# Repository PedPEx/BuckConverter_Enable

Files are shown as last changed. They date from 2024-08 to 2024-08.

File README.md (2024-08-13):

# BuckConverter with Enable Input (WIP!)
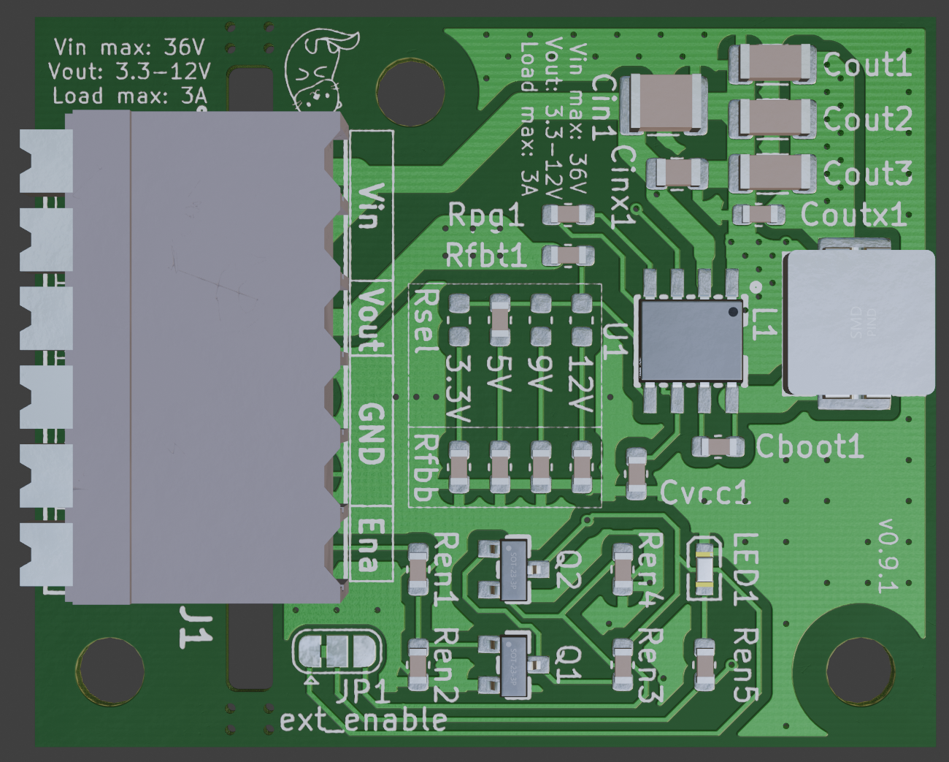
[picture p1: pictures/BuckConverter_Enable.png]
v0.9.1 a title


A BuckConverter based on the [Texas Instruments LM33630](https://www.ti.com/product/LMR33630). By default the converter is set to an output voltage of 5V and enabled permanently. Avaliable output levels are 3.3 V, 5 V, 9 V and 12 V. In order to select the desired output, only the corresponding `Rsel` 0 ohm resistor/connection has to be installed. 

The external enable input is enabled by cutting the builtin connection in `J1` and connectiong the solder bridge in the other direction. 

It's possible to use a [Weidmüller 1824460000 - LSF-SMT 3.50/06/90 3.5SN BK TU](https://catalog.weidmueller.com/catalog/Start.do?ObjectID=1824460000), a [PhoenixContact 1861975 - SPTAF 1 6-3,5-IL](https://www.phoenixcontact.com/de-de/produkte/leiterplattenklemme-sptaf-1-6-35-il-1861975) or a [screw terminal block from LCSC](https://www.lcsc.com/product-detail/Screw-Terminal-Blocks_DORABO-DB127S-3-5-6P-GN-S_C2997513.html) for J1. A standard 3.5 mm pitch pin header is also possible.

[Online BOM](https://htmlpreview.github.io/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)

---
**Note**

The pictures were rendered with the help of Blender and the [pcb2blender](https://github.com/30350n/pcb2blender) plugin and the HTML BOM was created withwith [InteractiveHtmlBom](https://github.com/openscopeproject/InteractiveHtmlBom).

---

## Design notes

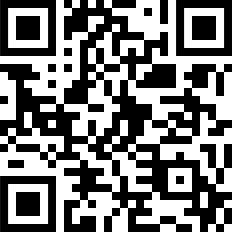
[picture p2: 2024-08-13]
pictures/QR.png

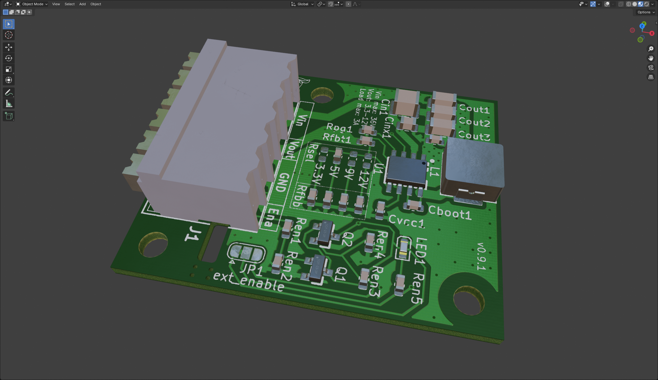
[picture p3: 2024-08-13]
pictures/BuckConverter_Enable2.png

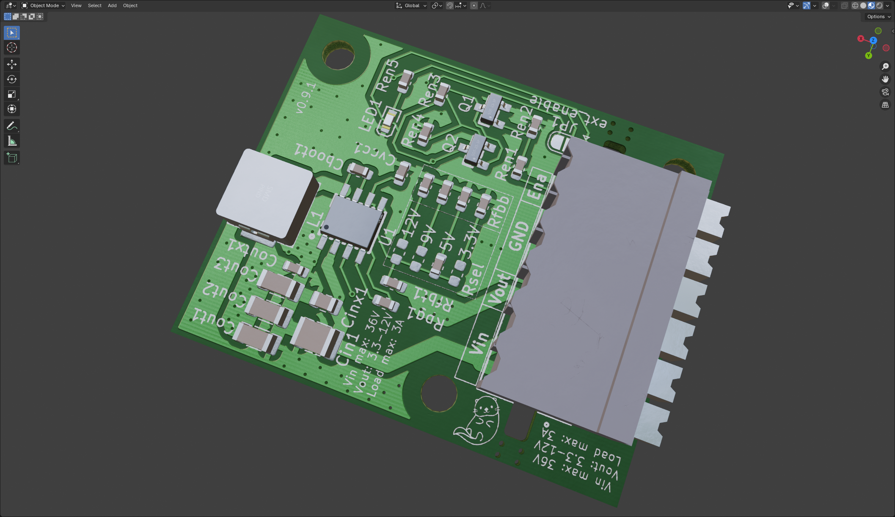
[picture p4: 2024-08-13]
pictures/BuckConverter_Enable1.png

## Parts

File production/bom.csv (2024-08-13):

Designator | Footprint | Quantity | Value | LCSC Part #
Cboot1, Coutx1 | 0603 | 2 | 100n
Cin1 | 1210 | 1 | 10u
Cinx1 | 0805 | 1 | 220n
Cout1, Cout2, Cout3 | 1206 | 3 | 47u
Cvcc1 | 0603 | 1 | 1u
J1 | 1824460000 - LSF-SMT 3.500690 3.5SN BK TU | 1 | 1824460000 - LSF-SMT 3.50/06/90 3.5SN BK TU | C19711765/C2997513
L1 | IND-SMD_L7.1-W6.6 | 1 | SPM6530T-100M | C112288
LED1 | LED0603-RD_BLUE | 1 | LTST-C193SBKT-5A | C364558
Q1 | SOT-23_L2.9-W1.3-P1.90-LS2.4-BR | 1 | PMBT3904,215 | C8667
Q2 | SOT-23_L2.9-W1.3-P1.90-LS2.4-BR | 1 | BSS84AK,215 | C127273
Ren1 | 0603 | 1 | 10k
Ren2, Ren3, Ren4, Rfbt1, Rpg1 | 0603 | 5 | 100k
Ren5 | 0603 | 1 | 2k
Rfbb_12V1 | 0603 | 1 | 9.09k
Rfbb_3.3V1 | 0603 | 1 | 43.2k
Rfbb_5V1 | 0603 | 1 | 24.9k
Rfbb_9V1 | 0603 | 1 | 12.4k
Rsel_5V1 | 0603 | 1 | 0
U1 | ESOP-8_L4.9-W3.9-P1.27-LS6.0-TL-EP | 1 | LMR33630ADDAR | C841384

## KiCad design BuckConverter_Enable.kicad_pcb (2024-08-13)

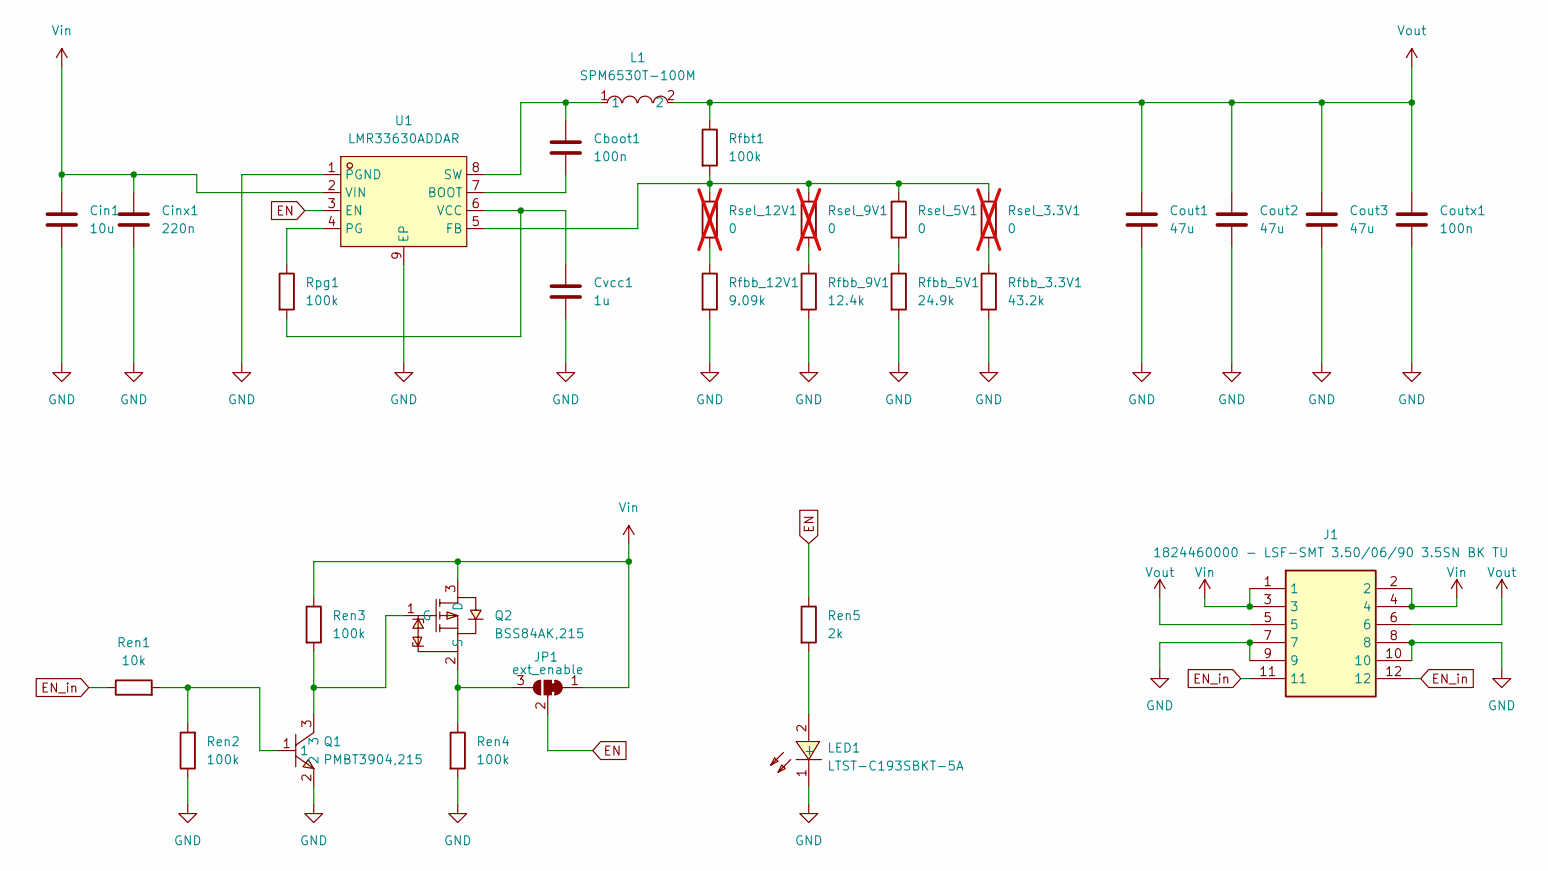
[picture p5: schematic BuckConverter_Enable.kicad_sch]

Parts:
Cboot1: 100n; C_0603_1608Metric
Cin1: 10u; C_1210_3225Metric
Cinx1: 220n; C_0805_2012Metric
Cout1, Cout2, Cout3: 47u; C_1206_3216Metric
Coutx1: 100n; C_0603_1608Metric
Cvcc1: 1u; C_0603_1608Metric
J1: 1824460000 - LSF-SMT 3.50/06/90 3.5SN BK TU; 1824460000 - LSF-SMT 3.500690 3.5SN BK TU; Manufacturer_Part_Number 1824460000; Mouser Part Number 470-1824460000
JP1: ext_enable; SolderJumper-3_P1.3mm_Bridged12_RoundedPad1.0x1.5mm
L1: SPM6530T-100M; IND-SMD_L7.1-W6.6; LCSC Part C112288
LED1: LTST-C193SBKT-5A; LED0603-RD_BLUE; LCSC Part C364558
Q1: PMBT3904,215; SOT-23_L2.9-W1.3-P1.90-LS2.4-BR; LCSC Part C8667
Q2: BSS84AK,215; SOT-23_L2.9-W1.3-P1.90-LS2.4-BR; LCSC Part C127273
Ren1: 10k; C_0603_1608Metric
Ren2, Ren3, Ren4: 100k; C_0603_1608Metric
Ren5: 2k; C_0603_1608Metric
Rfbb_3.3V1: 43.2k; C_0603_1608Metric
Rfbb_5V1: 24.9k; C_0603_1608Metric
Rfbb_9V1: 12.4k; C_0603_1608Metric
Rfbb_12V1: 9.09k; C_0603_1608Metric
Rfbt1: 100k; C_0603_1608Metric
Rpg1: 100k; C_0603_1608Metric
Rsel_3.3V1, Rsel_9V1, Rsel_12V1: 0; C_0603_1608Metric; not fitted
Rsel_5V1: 0; C_0603_1608Metric
U1: LMR33630ADDAR; ESOP-8_L4.9-W3.9-P1.27-LS6.0-TL-EP; LCSC Part C841384

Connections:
EN: JP1.2 (C), Ren5.1, U1.3 (EN)
EN_in: J1.11, J1.12, Ren1.1; also elsewhere on the board
GND: Cin1.2, Cinx1.2, Cout1.2, Cout2.2, Cout3.2, Coutx1.2, Cvcc1.2, J1.7, J1.8, J1.9, J1.10, LED1.1 (-), Q1.2, Ren2.1, Ren4.2, Rfbb_3.3V1.2, Rfbb_5V1.2, Rfbb_9V1.2, Rfbb_12V1.2, U1.1 (PGND), U1.9 (EP); also elsewhere on the board
unnamed: JP1.3 (B), Q2.2 (S), Ren4.1
unnamed: LED1.2 (+), Ren5.2
unnamed: Q1.1, Ren1.2, Ren2.2
unnamed: Q1.3, Q2.1 (G), Ren3.2
unnamed: Rfbb_3.3V1.1, Rsel_3.3V1.2
unnamed: Rfbb_5V1.1, Rsel_5V1.2
unnamed: Rfbb_9V1.1, Rsel_9V1.2
unnamed: Rfbb_12V1.1, Rsel_12V1.2
unnamed: Cboot1.2, U1.7 (BOOT)
unnamed: Rfbt1.2, Rsel_3.3V1.1, Rsel_5V1.1, Rsel_9V1.1, Rsel_12V1.1, U1.5 (FB)
unnamed: Rpg1.1, U1.4 (PG)
unnamed: Cboot1.1, L1.1, U1.8 (SW)
unnamed: Cvcc1.1, Rpg1.2, U1.6 (VCC)
Vin: Cin1.1, Cinx1.1, J1.1, J1.2, J1.3, J1.4, JP1.1 (A), Q2.3 (D), Ren3.1, U1.2 (VIN); also elsewhere on the board
Vout: Cout1.1, Cout2.1, Cout3.1, Coutx1.1, J1.5, J1.6, L1.2, Rfbt1.1; also elsewhere on the board

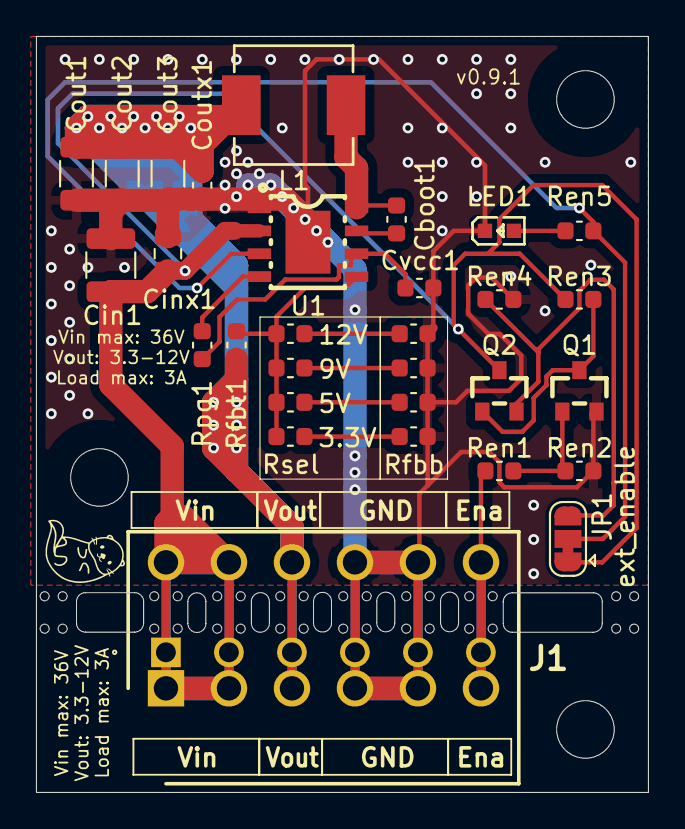
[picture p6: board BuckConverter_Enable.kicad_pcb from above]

Board: 2 copper layers, 34.0 x 42.0 mm, 31 parts (0 on the bottom side), 18 nets.

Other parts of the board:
J**: 1861975 - SPTAF 1 6-3,5-IL

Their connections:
EN_in: J**.11, J**.12; also elsewhere on the board
GND: J**.7, J**.8, J**.9, J**.10; also elsewhere on the board
Vin: J**.1, J**.2, J**.3, J**.4; also elsewhere on the board
Vout: J**.5, J**.6; also elsewhere on the board

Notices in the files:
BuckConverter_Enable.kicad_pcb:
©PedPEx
